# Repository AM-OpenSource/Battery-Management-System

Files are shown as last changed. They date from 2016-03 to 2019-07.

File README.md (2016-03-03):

Battery Management System
-------------------------

This project provides software for monitoring, control and charging of batteries
for a solar powered installation.

The motivation to build this arose from the poor performance, lack of
adequate control, lack of configuration for different battery types, and poor
user interface of commercially available BMS, at least for those reasonably
priced.

The system allows for up to three batteries to be managed separately. This
ensures that failed batteries may be isolated without adversely affecting the
other batteries, as could happen if batteries were connected in parallel. Also
note that if batteries were connected in parallel, the same type and age of
battery must be used, which would necessitate changing all batteries if one were
to fail.

The system also allows for up to two loads so that critical low current loads
may be kept running after high current loads are disconnected in the event
that all batteries fall to critically low charge levels.

The system uses several methods of tracking the State of Charge of each battery,
This is a notoriously difficult parameter to estimate. In a system with three
batteries one may be isolated long enough to allow the terminal voltage to
settle to a level that will allow SoC to be computed accurately.

In the long term it is intended to allow a variety of configurations for
charging and monitoring of batteries:

1. The common three phase charger is provided using PWM to reduce the voltage
   in the absorption phase. In float phase the charger is disconnected until the
   terminal voltage drops to a threshold value. Equalization is not provided.

2. An algorithm based on Interrupted Charge Control (ICC) is also provided to
   place batteries in rest when they have reached the gassing voltage and there
   are other batteries to be charged. This has advantages of:
   (a) better utilization of the charger among the batteries,
   (b) low EMI,
   (c) reduced gas generation.

A wide range of state information is stored on a removable memory, and also
transmitted over a serial link to allow a GUI to display the state accurately
and in detail.

A GUI is provided to allow control and observation of operations. The GUI has
been provided also on a BeagleBone Black card with a LCD touchscreen. This
is suitable for wall installation and draws very low power. For wireless
communications, XBees placed in point-point AT serial mode were successful.

Each of the six interfaces has a hardware overcurrent circuit breaker and low
voltage detector, as well as providing current and voltage measurements.

A central controller based on STM32F103 controls all interfaces and the MOSFET
switches directly. Hardware signals for overcurrent and low voltage are applied
directly to the MOSFET switches for rapid disconnect.

A data processing program is also provided to generate reports of various types
from the recorded performance data.

More information is available on [Jiggerjuice](http://www.jiggerjuice.info/electronics/projects/solarbms/solarbms-overview.html).

(c) K. Sarkies 12/09/2015

TODO

1. Improvement of MOSFET switch drivers to reduce EMI at higher rates.
2. MPPT regulator for the panel.
3. Some minor system issues:
* File date error
* Communications hang when errored messages sent.

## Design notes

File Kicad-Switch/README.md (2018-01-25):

Battery Management System Switch
--------------------------------

Version 2 of the PCB for the MOSFET switch matrix using SMD components.

Digital circuitry ensures that no two batteries are connected together, which
could cause damage if the state of charge between the batteries differs
significantly.

A diode matrix is used to provide power for the electronics. It ensures that
power is taken from the loads, or from the batteries if the loads are not
connected. This enables the firmware to keep track of the current drawn by
the local electronics.

The MOSFETs are driven by BJT PNP-NPN totem pole drivers. Three [Ideal Diodes](http://www.jiggerjuice.info/electronics/projects/power/ideal-diode.html) 
are also provided in the load circuits to prevent current flowing back to a
battery when a stronger battery is connected to a load. These circuits ensure
that additional voltage drops are kept small. The panel circuit will also
experience such a flow-back in circumstances when the panel voltage is
low. However prevention of this can be done in firmware as there is no value
connecting the panel to a battery if the panel voltage is low.

(c) K. Sarkies 19/01/2018

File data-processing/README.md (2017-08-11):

Battery Management System Data Processing Tools
-----------------------------------------------

Provides a GUI for analysing data text files generated by the BMS and also by
the BMS GUI. These are csv records consisting of an ID and several fields of
associated data.

The program scans the file for start and end time, and extracts a list of
record types. The user can then request a number of performance measures over
a specified time interval:

- average currents to allow analysis of energy budget.
- extracted measures with average, peak or sample within a subinterval, to a csv
  file for plotting.
- Split a large file into day files and merge with previous set of day files.
- Show some basic plots of battery and module currents and battery voltages.

QWT must be installed and the .pro file modified if necessary to point to it.

To compile this program, ensure that QT4.8 is installed.

make clean
qmake-qt4
make

Fields:

1. Time
1. Battery 1 Current
1. Battery 1 Voltage
1. Battery 1 Capacity Estimated
1. Battery 1 Operational State (Charged, Load, Isolated)
1. Battery 1 State of Charge (normal, low, critical)
1. Battery 1 Charging State (Bulk, Absorption, Float)
1. Battery 2 Current
1. Battery 2 Voltage
1. Battery 2 Capacity Estimated
1. Battery 2 Operational State (Charged, Load, Isolated)
1. Battery 2 State of Charge (normal, low, critical)
1. Battery 2 Charging State (Bulk, Absorption, Float)
1. Battery 3 Current
1. Battery 3 Voltage
1. Battery 3 Capacity Estimated
1. Battery 3 Operational State (Charged, Load, Isolated)
1. Battery 3 State of Charge (normal, low, critical)
1. Battery 3 Charging State (Bulk, Absorption, Float)
1. Load 1 Current
1. Load 1 Voltage
1. Load 2 Current
1. Load 2 Voltage
1. Panel 1 Current
1. Panel 1 Voltage
1. Temperature
1. Controls: (A=autotrack, R=recording, M=send measurements, D=debug, X=load
avoidance, 1-2-3=charger algorithm I=maintain isolation)
1. Switches: Battery number for Load 1, Load 2 and Panel. 0=not allocated.
1. Code for the Monitor decision made when allocating loads and panel.
1. Indicator codes for each of the six interfaces: Battery 1-2-3, Load 1-2,
Panel. Two subfields for each: O for overload, U for undervoltage.
1. Fields for User defined debug messages

(c) K. Sarkies 17/11/2016

TODO

1. Compile under QT5 or later.

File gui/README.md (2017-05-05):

Battery Management System GUI
-----------------------------

The GUI provides a means of displaying performance and status information in
numerical and graphical form, setting up data recording on the remote system
and configuring the system.

It can connect via serial (directly or using a serial to USB adapter), or by
TCP/IP when connected through an intermediate machine that maps the serial
interface to a TCP/IP interface. This makes it possible to monitor the system
remotely over Internet.

Currently the constant SERIAL in the header power-management.h is defined if
the serial version is desired. Otherwise it is left undefined to use the TCP
version.

QWT must be installed and the .pro file modified if necessary to point to it.

To compile this program, ensure that QT5 is installed.

make clean
qmake
make

Call with power-management [options]

If SERIAL is defined the following apply:

-P   port (/dev/ttyUSB0 default)

-b   baudrate (from 2400, 4800, 9600, 19200, 38400 default, 57600, 115200)

Otherwise if SERIAL is not defined the following apply:

-a   TCP address (192.168.2.16 default)

-p   TCP port (6666 default)

More information is available on [Jiggerjuice](http://www.jiggerjuice.info/electronics/projects/solarbms/solarbms-gui.html).

(c) K. Sarkies 05/05/2017

TODO

1. File - add file info (date).
2. Download feature (may cause saturation of the comms interface).
3. Make into a single compile binary for serial and TCP versions.

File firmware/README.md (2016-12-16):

Battery Management System Firmware
----------------------------------

Version: 1.0.0

The firmware is written for an STM32F103 ARM Cortex M3 microcontroller and uses
specific hardware published along with this firmware.

The firmware uses libopencm3 for hardware drivers, FreeRTOS for task management
and ChaN FatFs for managing the local storage filesystem, along with an
adaption of the driver code by Martin Thomas for SDSC/MMC SPI drivers to
incorporate libopencm3 and FreeRTOS.

Several tasks are defined to manage:

- command and data communications,
- storage,
- battery state monitoring,
- charge control,
- measurement,
- program execution watchdog and error recovery.

It is designed to be adapted to allow CANopen to manage communications with an
external PC, in case the project is further developed.

The hardware component values set the various scaling factors for voltages and
currents, and these may change for different hardware versions.

Three versions are here represented. Each refers to slightly different
voltage and current scales in the measurement header for the interface PCB
version. Currently version 3 is being used and is the default.
It is compiled with 'make VERSION=x' where x = 2 or 3. Version 1 is obsolete.

The charger algorithm is referred to as "Pulse Charge". This aims to avoid the
PWM switching needed to maintain a constant absorption phase voltage, which
reduces EMI problems and also reduces overcharging by keeping the battery charge
voltages as low as possible. The Pulse Charge algorithm is an adaptation of 
the Interrupted Charge Control, Intermittent Charge, and Three Phase algorithms
reported in the literature, providing efficient and independent charging of
multiple batteries from an uncontrolled variable power source such as that found
in solar and aeolian systems.

Compilation is done on Linux using the arm-none-eabi compiler package and by
command line "make" using a makefile. The makefile needs to be modified to suit
the installation of libraries: change the macro LIBRARY_DIR for libopencm3,
FREERTOS_DIR for FreeRTOS and FATFSDIR for ChaN FAT.

The ChaN FAT library is provided as it has inbuilt modifications to allow use
with libopencm3. If ChaN FAT is upgraded, the file sd_spi_loc3_stm32_freertos.c
must be retained (or adapted as necessary).

More information is available on [Jiggerjuice](http://www.jiggerjuice.info/electronics/projects/solarbms/solarbms-software.html)

(c) K. Sarkies 10/12/2016

BUGS

1. The file directory list command results in very slow transmission, about one
   entry per second.
2. File dates are sometimes wrong.

TODO

1. Firmware upload - from within the program. Base on stm32flash.
2. Comms - test queue space available for each data message to send.
3. File - add file info (date) to GUI.
4. Measurement - Increase switching speed to 25kHz. May need hardware changes.

BUGS

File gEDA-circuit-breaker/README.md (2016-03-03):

Battery Management System Circuit Breaker
-----------------------------------------

PCB for the interfaces between the external power sources and loads, and the
internal switch.

The current passes through a current sense resistor, and voltage is measured
with an offset differential amplifier, but there is no direct on-board
connection between the power and circuit commons. This is commoned elsewhere
(in the switch).

The circuit breaker passes a signal back to the interconnect board where it
is used for hardware isolation of the particular switch. For this reason the
correct power source and circuit interfaces must be used together, otherwise
the circuit breaker will be ineffective. Similarly for the low voltage
detection. The circuit breaker is based on those proposed by [R Paisley](http://home.cogeco.ca/~rpaisley4/CircuitBreaker05.html).

(c) K. Sarkies 31/08/2014

TODO:

1. The reference voltage to the current monitor is taken from the 2.5V
reference for the voltage measurement circuit. However this latter uses the
battery ground rather than the local ground, and a small bias voltage can
be present. Ideally the current monitor should have its own reference voltage.

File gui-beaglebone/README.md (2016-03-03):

Battery Management System GUI for BeagleBone Touch Screen
---------------------------------------------------------

This is a cut-down version of the GUI for PC intended for use with a BeagleBone
touch screen for field monitoring and configuration of the BMS.

It only connects via serial (directly or using a serial to USB adapter).

To compile this program, ensure that QT4 is installed on the BeagleBone and
also that qextserialport has been downloaded and unzipped into a suitable
directory. It doesn't need to be compiled or installed, as the GUI will
incorporate it directly into the compile and link procedure.

The file power-management.pro must be modified to point to the directory
holding qextserialport.

More information is available on [Jiggerjuice](http://www.jiggerjuice.info/electronics/projects/solarbms/solarbms-gui.html).

(c) K. Sarkies 29/09/2014

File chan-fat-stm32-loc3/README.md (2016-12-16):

This is an adaptation of ChaN's FatFS FAT filesystem library based on v0.12.

Common files are ff.c, ff.h, ffconf.h, integer.h, diskio.h. These should be
updated when a new version of ChaN FAT library is released. Ensure that any
changes to ffconf.h are reflected in the new version.

The remaining files adapt the library to the hardware being used, to FreeRTOS
and to libopencm3. Some changes to these may be necessary if the ChaN FAT API
changes.

Currently the makefile calls on sd_spi_loc3_stm32_freertos.c. The other files
are older attempts that have been retained for possible future reference
but are outdated.

More information is available on [Jiggerjuice](http://www.jiggerjuice.info/electronics/projects/solarbms/solarbms-software.html).

(c) K. Sarkies 10/12/2016

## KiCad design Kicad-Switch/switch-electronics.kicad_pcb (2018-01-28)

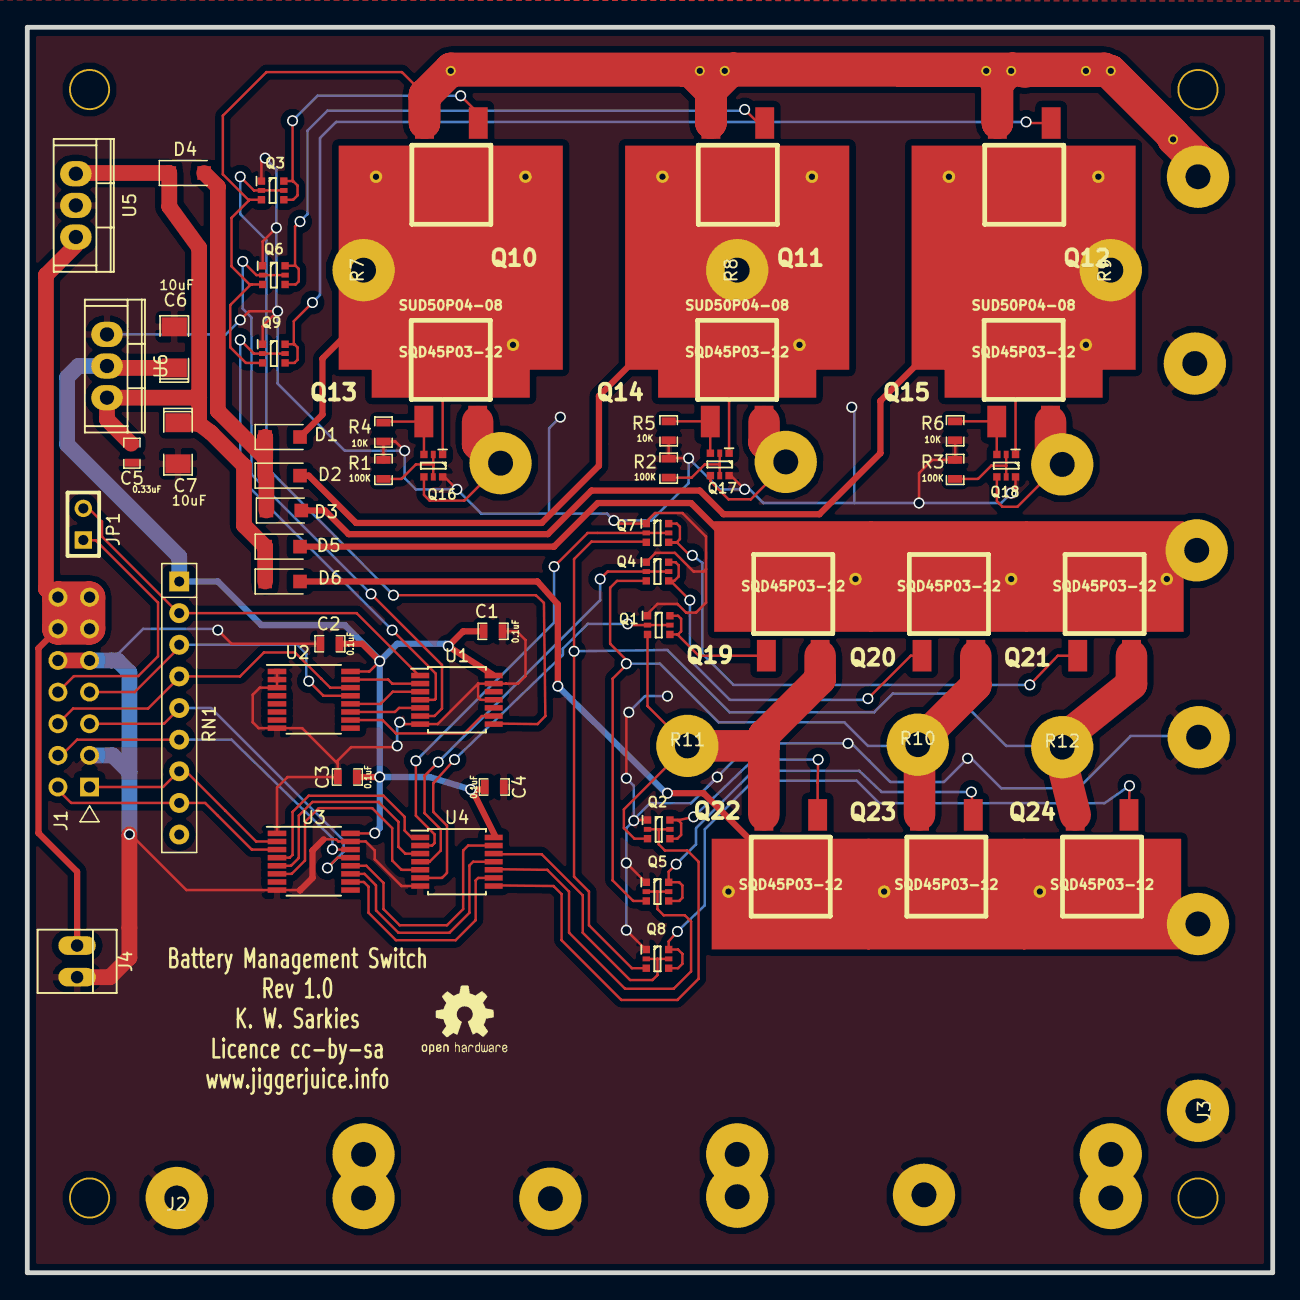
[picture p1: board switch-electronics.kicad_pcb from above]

Board: 2 copper layers, 100.0 x 100.0 mm, 69 parts (0 on the bottom side), 62 nets.

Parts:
C1, C2, C3, C4: 0.1uF; SM0603_Capa
C5: 0.33uF; SM0603_Capa
C6, C7: 10uF; SM1206POL
D1, D2, D3, D4: 1N4001; D_SOD-123F
D5, D6: 2N5819; D_SOD-123F
J1: Conn_02x07_Odd_Even; header-14-v
J2, J3: Screw_Terminal_01x06; Screw_Terminal_Six
J4: Conn_01x02; PINHEAD1-2
J5, J6, J7, J8, J9, J10, J11, J12: Conn_01x01; THROUGHVIA
JP1: Jumper_NO_Small; SIL-2
Q1, Q2, Q3, Q4, Q5, Q6, Q7, Q8, Q9: BC847BPDW1; SOT-363
Q10, Q11, Q12: SUD50P04-08; TO252-HS-Large
Q13, Q14, Q15, Q19, Q20, Q21, Q22, Q23, Q24: SQD45P03-12; TO252-HS-Small
Q16, Q17, Q18: BC856BDW1; SOT-363
R1, R2, R3: 100K; SM0603_Resistor
R4, R5, R6: 10K; SM0603_Resistor
R7, R8, R9: 0; Link_1
R10: 0; Link_3
R11: 0; Link_2
R12: 0; Link_4
RN1: R_Network08; R_Array_SIP9
U1, U4: 74HC04; TSSOP-14
U2, U3: 74LS139; TSSOP-16
U5: LM7809_TO220; TO-220
U6: LM1086-3.3; TO-220

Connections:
9V: J1.11, J1.12, J1.13, J1.14, J4.1, U5.3
B1: Q1.3, Q2.3, Q19.2, Q22.2, R11.1
B1L1: Q1.4, Q1.6, Q19.1
B1L2: Q2.4, Q2.6, Q22.1
B1M1: Q3.4, Q3.6, Q10.1
B2: Q4.3, Q5.3, Q20.2, Q23.2, R10.1
B2L1: Q4.4, Q4.6, Q20.1
B2L2: Q5.4, Q5.6, Q23.1
B2M1: Q6.4, Q6.6, Q11.1
B3: Q7.3, Q8.3, Q21.2, Q24.2, R12.1
B3L1: Q7.4, Q7.6, Q21.1
B3L2: Q8.4, Q8.6, Q24.1
B3M1: Q9.4, Q9.6, Q12.1
GND: C1.2, C2.2, C3.2, C4.2, C5.2, C6.2, C7.2, J1.3, J1.9, J1.10, J2.1, J2.3, J2.5, J3.1, J3.3, J3.5, J4.2, Q1.1, Q2.1, Q3.1, Q4.1, Q5.1, Q6.1, Q7.1, Q8.1, Q9.1, Q16.6, Q17.6, Q18.6, R1.2, R2.2, R3.2, R4.2, R5.2, R6.2, U1.7, U1.11, U1.13, U2.1, U2.2, U2.3, U2.8, U3.1, U3.8, U3.15, U4.7, U5.2, U6.1
M1: J3.6, J5.1, J6.1, J7.1, J8.1, J9.1, J10.1, J11.1, J12.1, Q3.3, Q6.3, Q9.3, Q10.2, Q11.2, Q12.2
unnamed: C5.1, C7.1, D4.1, D5.1, D6.1, U5.1, U6.3
unnamed: D1.1, D2.1, D3.1, D4.2
unnamed: D1.2, Q10.3, Q13.3, Q16.1, R7.1
unnamed: D2.2, Q11.3, Q14.3, Q17.1, R8.1
unnamed: D3.2, Q12.3, Q15.3, Q18.1, R9.1
unnamed: D5.2, J3.4, Q19.3, Q20.3, Q21.3
unnamed: D6.2, J3.2, Q22.3, Q23.3, Q24.3
unnamed: J1.1, RN1.7, U3.2
unnamed: J1.2, RN1.8, U3.3
unnamed: J1.4, RN1.6, U3.14
unnamed: J1.5, RN1.5, U3.13
unnamed: J1.6, RN1.4, U2.14
unnamed: J1.7, RN1.3, U2.13
unnamed: J1.8, JP1.1
unnamed: J2.2, R7.2
unnamed: J2.4, R8.2
unnamed: J2.6, R9.2
unnamed: JP1.2, RN1.2, U1.1
unnamed: Q1.2, Q1.5, U4.6
unnamed: Q2.2, Q2.5, U4.8
unnamed: Q3.2, Q3.5, U1.8
unnamed: Q4.2, Q4.5, U4.4
unnamed: Q5.2, Q5.5, U4.10
unnamed: Q6.2, Q6.5, U1.6
unnamed: Q7.2, Q7.5, U4.2
unnamed: Q8.2, Q8.5, U4.12
unnamed: Q9.2, Q9.5, U1.4
unnamed: Q13.1, Q16.3, R4.1
unnamed: Q13.2, Q16.4, R11.2
unnamed: Q14.1, Q17.3, R5.1
unnamed: Q14.2, Q17.4, R10.2
unnamed: Q15.1, Q18.3, R6.1
unnamed: Q15.2, Q18.4, R12.2
unnamed: Q16.2, Q16.5, R1.1
unnamed: Q17.2, Q17.5, R2.1
unnamed: Q18.2, Q18.5, R3.1
unnamed: U1.2, U2.15
unnamed: U1.3, U2.12
unnamed: U1.5, U2.11
unnamed: U1.9, U2.10
unnamed: U3.4, U4.1
unnamed: U3.5, U4.3
unnamed: U3.6, U4.5
unnamed: U3.10, U4.9
unnamed: U3.11, U4.11
unnamed: U3.12, U4.13
VCC: C1.1, C2.1, C3.1, C4.1, C6.1, RN1.1, U1.14, U2.16, U3.16, U4.14, U6.2

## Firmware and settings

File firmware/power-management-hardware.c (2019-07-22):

/** @defgroup Hardware_file Hardware

@brief Hardware Setup

This configures all peripherals for the program and provides some
convenience functions for accessing the hardware.

Along with the file board-defs.h that provides specific defines for the
processor board in use, this file abstracts the hardware from the rest
of the program and allows rapid adaption to other board archictectures.

Note that the STM32F series of ARM microcontrollers are used because of
their provision of 12 bit A/D.

Flash write code adapted from code by Damian Miller.

Initial 29 September 2013
Updated 19 July 2019
Replace timer_reset(TIM1) with rcc_periph_reset_pulse(RST_TIM1) according to issue #709.
*/

/*
 * This file is part of the battery-management-system project.
 *
 * Copyright 2013 K. Sarkies <ksarkies@internode.on.net>
 *
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
 * You should have received a copy of the GNU Lesser General Public License
 * along with this program.  If not, see <http://www.gnu.org/licenses/>.
 */

/**@{*/

/* Set this define if the SWD debug is to be used. It will disable some ports
so must be commented out for normal use. */
//#define USE_SWD

#include <stdint.h>
#include <stdbool.h>

#include "power-management-board-defs.h"
#include "power-management-hardware.h"

/* libopencm3 driver includes */
#include <libopencm3/stm32/iwdg.h>
#include <libopencm3/stm32/rcc.h>
#include <libopencm3/stm32/rtc.h>
#include <libopencm3/stm32/adc.h>
#include <libopencm3/stm32/gpio.h>
#include <libopencm3/stm32/timer.h>
#include <libopencm3/stm32/dma.h>
#include <libopencm3/stm32/usart.h>
#include <libopencm3/stm32/flash.h>
#include <libopencm3/cm3/nvic.h>
#include <libopencm3/cm3/scb.h>
#include <libopencm3/cm3/systick.h>

/* Scheduler includes. */
#include "FreeRTOS.h"
#include "queue.h"
#include "semphr.h"

/* Globals */
extern uint32_t __configBlockStart;
extern uint32_t __configBlockEnd;

/* Local Prototypes */
static void adcSetup(void);
static void dmaAdcSetup(void);
static void iwdgSetup(void);
static void gpioSetup(void);
static void usartSetup(void);
static void clockSetup(void);
static void systickSetup();
static void pwmSetup(void);

/* Local Variables */
static uint8_t pwmCount;
static uint32_t v[NUM_CHANNEL]; /* Buffer used by DMA to dump A/D conversions */
static uint8_t adceoc;          /* A/D end of conversion flag */
static uint32_t lostCharacters; /* Number of characters lost due to queue full */

/* FreeRTOS queues and intercommunication variables defined in Comms */
extern xQueueHandle commsSendQueue, commsReceiveQueue, commsEmptySemaphore;

/* Time variables needed when systick is the timer */
static uint32_t secondsCount;
static uint32_t millisecondsCount;

/* This is provided in the FAT filesystem library */
extern void disk_timerproc();

/*--------------------------------------------------------------------------*/
/** @brief Initialise the hardware

*/

void prvSetupHardware(void)
{
    clockSetup();
    gpioSetup();
    usartSetup();
    pwmSetup();
    dmaAdcSetup();
    adcSetup();
    systickSetup();
    rtc_auto_awake(RCC_LSE, 0x7fff);
    iwdgSetup();
    secondsCount = 0;
    millisecondsCount = 0;
}

/*--------------------------------------------------------------------------*/
/** @brief Return the A/D Conversion Results

Note the channel must be less than the number of channels in the A/D converter.

@param[in] channel: uint8_t A/D channel to be retrieved from the DMA buffer.
@returns uint32_t last value measured by the A/D converter.
*/

uint32_t adcValue(uint8_t channel)
{
    if (channel > NUM_CHANNEL) return 0;
    return v[channel];
}

/*--------------------------------------------------------------------------*/
/** @brief Return and Reset the A/D End of Conversion Flag

This must be retrieved from the ISR as the hardware EOC doesn't always change
at the end of a conversion (when multiple conversions take place).

@returns uint8_t boolean true if the flag was set; false otherwise.
*/

uint8_t adcEOC(void)
{
    if (adceoc > 0)
    {
        adceoc = 0;
        return 1;
    }
    return 0;
}

/*--------------------------------------------------------------------------*/
/** @brief Read and Return Interface Error Indicators

The indicator settings are read and combined, with battery1, battery2,
battery3, load1, load2, panel from lsb up, and overload followed by
undervoltage for each.

Each bit is zero if the indicator is on, 1 if it is off.

@returns uint16_t binary set of indicator settings.
*/
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

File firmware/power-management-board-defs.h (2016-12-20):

/* STM32F1 Power Management for Solar Power

Definitions for the Selected Microcontroller Board.

Either the ET-STM32F103 or the ET-STAMP-STM board can be used.

Initial 23 September 2013

*/

/*
 * This file is part of the battery-management-system project.
 *
 * Copyright 2013 K. Sarkies <ksarkies@internode.on.net>
 *
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
 * You should have received a copy of the GNU Lesser General Public License
 * along with this program.  If not, see <http://www.gnu.org/licenses/>.
 */

#ifndef POWER_MANAGEMENT_BOARD_H_
#define POWER_MANAGEMENT_BOARD_H_

/* A/D Converter Channels */

#if defined USE_ET_STM32F103

#define ADC_CHANNEL_BATTERY1_CURRENT    0
#define ADC_CHANNEL_BATTERY1_VOLTAGE    1
#define ADC_CHANNEL_BATTERY2_CURRENT    2
#define ADC_CHANNEL_BATTERY2_VOLTAGE    3
#define ADC_CHANNEL_BATTERY3_CURRENT    10
#define ADC_CHANNEL_BATTERY3_VOLTAGE    11
#define ADC_CHANNEL_PANEL_CURRENT       4
#define ADC_CHANNEL_PANEL_VOLTAGE       5
#define ADC_CHANNEL_LOAD1_CURRENT       12
#define ADC_CHANNEL_LOAD1_VOLTAGE       13
#define ADC_CHANNEL_LOAD2_CURRENT       14
#define ADC_CHANNEL_LOAD2_VOLTAGE       15
#define ADC_CHANNEL_TEMPERATURE         6

#elif defined USE_ET_STAMP_STM32

#define ADC_CHANNEL_BATTERY1_CURRENT    0
#define ADC_CHANNEL_BATTERY1_VOLTAGE    1
#define ADC_CHANNEL_BATTERY2_CURRENT    2
#define ADC_CHANNEL_BATTERY2_VOLTAGE    3
#define ADC_CHANNEL_BATTERY3_CURRENT    4
#define ADC_CHANNEL_BATTERY3_VOLTAGE    5
#define ADC_CHANNEL_PANEL_CURRENT       6
#define ADC_CHANNEL_PANEL_VOLTAGE       7
#define ADC_CHANNEL_LOAD1_CURRENT       10
#define ADC_CHANNEL_LOAD1_VOLTAGE       11
#define ADC_CHANNEL_LOAD2_CURRENT       12
#define ADC_CHANNEL_LOAD2_VOLTAGE       13
#define ADC_CHANNEL_TEMPERATURE         14

#else
#error "unsupported board"
#endif

/* Controls and Status Signals */

#if defined USE_ET_STM32F103

/* The switch control code assumes the control pairs are in order */
#define SWITCH_CONTROL_PORT             GPIOB
#define SWITCH_CONTROL_SHIFT            8

/* The overcurrent reset ports */
#define BATTERY1_OVERCURRENT_RESET_PORT GPIOC
#define BATTERY1_OVERCURRENT_RESET_BIT  GPIO11
#define BATTERY2_OVERCURRENT_RESET_PORT GPIOA
#define BATTERY2_OVERCURRENT_RESET_BIT  GPIO7
#define BATTERY3_OVERCURRENT_RESET_PORT GPIOB
#define BATTERY3_OVERCURRENT_RESET_BIT  GPIO0
#define LOAD1_OVERCURRENT_RESET_PORT    GPIOB
#define LOAD1_OVERCURRENT_RESET_BIT     GPIO3
#define LOAD2_OVERCURRENT_RESET_PORT    GPIOB
#define LOAD2_OVERCURRENT_RESET_BIT     GPIO7
#define PANEL_OVERCURRENT_RESET_PORT    GPIOC
#define PANEL_OVERCURRENT_RESET_BIT     GPIO8

#define BATTERY1_STATUS_PORT            GPIOC
#define BATTERY1_STATUS_SHIFT           9
#define BATTERY2_STATUS_PORT            GPIOC
#define BATTERY2_STATUS_SHIFT           12
#define BATTERY3_STATUS_PORT            GPIOC
#define BATTERY3_STATUS_SHIFT           6
#define PANEL_STATUS_PORT               GPIOB
#define PANEL_STATUS_SHIFT              14
#define LOAD1_STATUS_PORT               GPIOB
#define LOAD1_STATUS_SHIFT              1
#define LOAD2_STATUS_PORT               GPIOB
#define LOAD2_STATUS_SHIFT              4

#elif defined USE_ET_STAMP_STM32

/* The switch control code assumes the control pairs are in order */
#define SWITCH_CONTROL_PORT             GPIOC
#define SWITCH_CONTROL_SHIFT            6

/* The overcurrent reset ports */
#define BATTERY1_OVERCURRENT_RESET_PORT GPIOA
#define BATTERY1_OVERCURRENT_RESET_BIT  GPIO13
#define BATTERY2_OVERCURRENT_RESET_PORT GPIOA
#define BATTERY2_OVERCURRENT_RESET_BIT  GPIO14
#define BATTERY3_OVERCURRENT_RESET_PORT GPIOA
#define BATTERY3_OVERCURRENT_RESET_BIT  GPIO15
#define LOAD1_OVERCURRENT_RESET_PORT    GPIOC
#define LOAD1_OVERCURRENT_RESET_BIT     GPIO12
#define LOAD2_OVERCURRENT_RESET_PORT    GPIOC
#define LOAD2_OVERCURRENT_RESET_BIT     GPIO13
#define PANEL_OVERCURRENT_RESET_PORT    GPIOC
#define PANEL_OVERCURRENT_RESET_BIT     GPIO5

#define BATTERY1_STATUS_PORT            GPIOB
#define BATTERY1_STATUS_SHIFT           0
#define BATTERY2_STATUS_PORT            GPIOA
#define BATTERY2_STATUS_SHIFT           11
#define BATTERY3_STATUS_PORT            GPIOB
#define BATTERY3_STATUS_SHIFT           4
#define PANEL_STATUS_PORT               GPIOB
#define PANEL_STATUS_SHIFT              6
#define LOAD1_STATUS_PORT               GPIOB
#define LOAD1_STATUS_SHIFT              8
#define LOAD2_STATUS_PORT               GPIOB
#define LOAD2_STATUS_SHIFT              10

#else
#error "unsupported board"
#endif

/* GPIO Port Settings */

#if defined USE_ET_STM32F103
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

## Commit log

2015-10-07 GUI bug that limited battery capacity setting in config to 40% minimum. Set back to 0.
2016-03-02 Data Processing incorporate display of temperature
2016-04-04 GUI: correct bug where serial device combobox had no effect.
    [power-management-main.h]
2016-11-10 Update to latest libopencm3. Update to latest ChaN FatFS Update main file documentation. FreeRTOS updated also but API has not changed and is not reflected here. TODO fix raft of warnings from FreeRT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
    [diskio.h, power-management-hardware.c]
2016-11-10 Fix many warning messages from FreeRTOS and some other places. Only warnings now are forced comments.
    [power-management-hardware.c, power-management-measurement.c, power-management-objdic.h]
2016-11-15 Setup of Doxygen documentation structure for firmware Initial documentation of Monitor, Charger, Measurement and Communications tasks.
2016-11-19 Changes to the monitor program to prevent rapid switching back and forth of charger/load allocations when one battery is low or critical. Change to prevent rapid switching of load allocation when cha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
    [power-management-objdic.h]
2016-11-19 Rescale GUI configure window calibration tab.
2016-11-30 Monitor: reduce threshold for turning off charger on low panel voltage. Fix some documentation and inconsistencies. Add debug statements to track down SoC discrepencies. Overall: update to latest lib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
    [power-management-comms.h]
2016-11-30 Add a decisionStatus to the monitor when the charger is disconnected by reason of low voltage.
2016-12-02 Firmware: Introduce a millisecond counter and correct the accumulated charge computation in power-system-measurement to use correct time lapse between measurements of currents. Change a few names for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
    [power-management-comms.h, power-management-hardware.c, power-management-measurement.c]
2016-12-20 Modify BMS monitoring to set SoC to 70% when rest phase is reached. Remove code added earlier, aimed at stopping thrashing in case of a low battery and add hysteresis. Increase time in isolation to 4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
    [power-management-board-defs.h, sd_spi_loc3_stm32_freertos.c]
2017-01-04 Change to file operations to replace a processor I/O port number with a macro.
    Bump version number to 1.04
    [power-management-objdic.h, sd_spi_loc3_stm32_freertos.c]
2017-01-09 Correct dumb error in last commit that didn't handle the case where the battery charger was disconnected.
2017-01-09 Minor corrections to comms to null filenames when files are closed. Some small documentation changes.
    [power-management-hardware.c, power-management-objdic.h]
2017-04-11 firmware: Convert battery state variables to be encapsulated into a battery state struct. This is basically a change in naming only.
2017-04-11 Firmware: modify two battery case by incorporating a new health state of "weak" that causes the charger to be prioritized and all loads to be removed. If the charger is disconnected (usually at night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
2017-04-12 Firmware: Modify remaining cases of more than two batteries to account for weak battery decisions and charger off situations. The charger off is now a boolean variable set when the charger is disconn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
2017-04-16 Firmware: modify monitor logic to unravel and display flow more clearly. Still needs checking. A great deal of repetition would benefit from better structuring.
2017-04-18 Firmware monitor: large scale refactoring of decision block. This is intermediate with the intention of combining two battery and more than two battery cases. Charger: move decision to set SoC to 70%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
2017-04-19 Firmware: Add an additional decision to deallocate the load if the loaded battery becomes low.
2017-04-21 Firmware: remove charger from battery when disabling the charger. Do not restore a battery labelled weak until it is charged to rest phase. This will avoid thrashing in the event of an ailing battery.
    [power-management-objdic.h]
2017-04-22 Firmware: Add a check after loads allocated. If the battery under load is low check for a better battery even if it is isolated. Similarly with charger, check for a lower battery even if it is isolat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
    [power-management-objdic.h]
2017-04-26 Firmware: Mark battery as weak when voltage falls below a preset voltage (11V). Remove a dynamic test for missing battery as it may erroneously be so labelled by the hardware when the battery charge 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
    [power-management-objdic.h]
2017-05-04 GUI: fix problems with parameter recognition and source address/port specification for the TCP version
    [power-management-main.h]
2017-07-21 Data processing: add feature to extract battery charging behaviour, especially near the float limit. Add feature to extract solar current while batteries are in bulk charging phase.
2017-07-21 Firmware charger: do not allow transfer to float stage to occur until absorption phase current is below the limit for a number (10) of consecutive cycles.
2017-07-21 Firmware monitor: a number of doc and code changes to attempt to correct tendency of the new monitor algorithms to allocate loads to charging battery,
    [power-management-objdic.h]
2017-08-13 firmware: handle missing batteries better to avoid allocations to them.
    [power-management-hardware.c]
2017-08-14 Firmware: further fixes to monitor to deal with allocation of charger and loads in the case of one battery.
2017-08-26 Firmware Version 1.07. More corrections to handling of missing batteries.
    [power-management-objdic.h]
2018-01-25 Switch PCB: first Kicad version complete, not yet verified.
    [switch-electronics.kicad_pcb, switch-electronics.sch, switch-mosfet.sch]
2018-01-26 Complete PCB apart from some points that Kicad doesn't consider to be connected. Reduce size to 100mmx100mm to reduce manufacturing costs.
    [switch-electronics.kicad_pcb, switch-electronics.sch, switch-mosfet.sch]
2018-01-28 Managed to convince Kicad to agree that certain nets were connected to their pads, after adding multiple overlay tracks. Now DRC error free. Adjusted tracks and grounds to ensure that most blank area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
    [bms-switch.gbl, bms-switch.gbo, bms-switch.gbr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]
2019-07-21 Replace timer_reset due to change in libopencm3 API Create FreeRTOS task start functions in six modules to move FreeRTOS calls out of the main program into the modules. Change taskDelete calls to use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
    [diskio.h]

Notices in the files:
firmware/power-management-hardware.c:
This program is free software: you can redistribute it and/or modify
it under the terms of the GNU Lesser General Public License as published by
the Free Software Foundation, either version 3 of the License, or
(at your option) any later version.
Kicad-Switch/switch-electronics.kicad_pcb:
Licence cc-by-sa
